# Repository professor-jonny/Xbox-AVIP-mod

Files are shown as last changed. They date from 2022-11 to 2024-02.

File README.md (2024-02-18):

# Xbox Avip mod
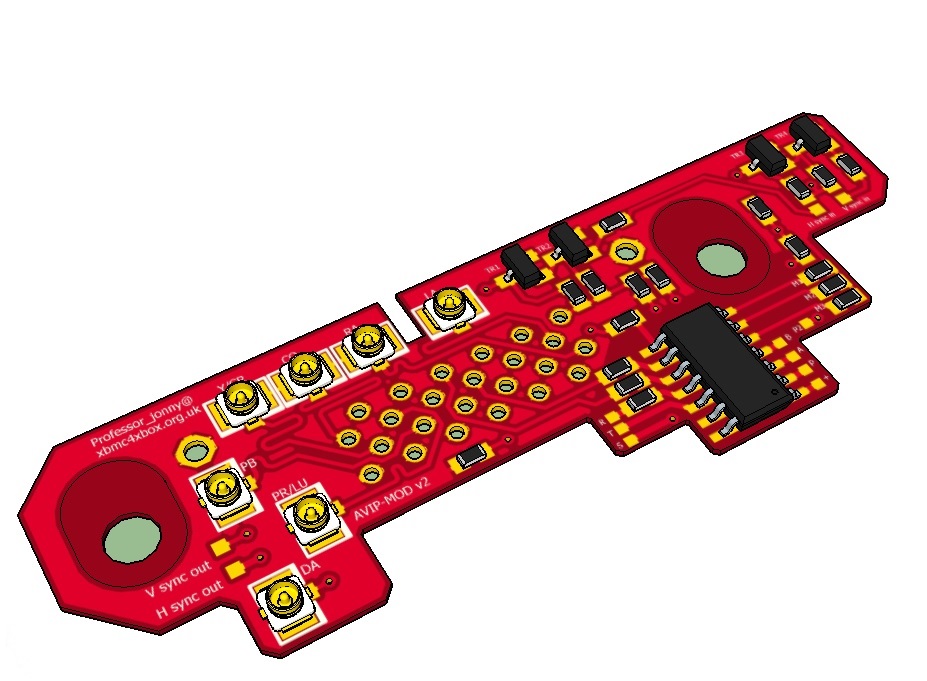
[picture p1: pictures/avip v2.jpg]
AVIP BRD


## Project Info
We all know that modern TV's are going away from component and composite video inputs in favor of newer technologies such as HDMI because of this there has been many people attempting various mods some great, some sketchy and some down right wrong.

This project started as I have seen a few people damage their Xbox consoles by attempting VGA and HDMI mods or made such a bad job of it that that I decided something needed to be done and I set out to make up a basic QSB to break out signals that you can use within the console to attached to external connectors or for use with an internal video adaptor solution.
Design goals were to be simple quick to install and have no complicated binary logic external switches to select the video modes.

The design also includes a buffer circuit to drive the internal h and v sync signals to 5v to give you proper VGA compliant signals with a suitable bios.

The system includes a PICAXE microcontroller to be able to switch video modes and other trickery, I designed it using this over a traditional microcontroller for ease of a user to modify using a three wire serial connection (in circuit) and partly from my lack of programming skills and time.
The PICAXE system enables any one to reprogram it without too much hassle and with minimal programming knowledge, both flow chart and basic programs are provided as samples that are easy to follow and understand.

I have also designed some breakout boards to join to the AVIP mod board, or you could use get IPEX/ U.FL to solder tails to connect to some sort of internal adaptor or converter in my perisomal Xbox I milled pads to place IPEX/ U.FL sockets on a component to HDMI adaptor.

I had double ended U.FL /IPEX Connectors made for this project officially the connectors are actually 50 ohm but were made with 75 ohm cable so the impedances are not perfect but it was the only aspect of the project I was not happy with, I planned to further update this project with a flex or FFC cable between boards but I'm unsure on impedance matching and the design of such a cable if someone can offer us some help with that I would be very grateful.

I realize at 720p the bandwidth can tip 75MHZ so the cable will need to be designed with microstrip or stripline transmission mitred bends or as such but I don't know much about the property's of these FFC cables or FlexPCB's or their connectors.

## Rational over other mods
I realize that there are other mods that offer better solutions or something of a similar goal such as native digital output or internal component to HDMI etc... but many are not simple or cost effective.
Many require de-soldering the original AVIP connector or micro soldering and for many people this is something that is beyond their skill set but a QSB solution is very noob friendly and hence my project.

## Features
The AVIP  mod has the following features:
  * Pluggable RF connectors for AV signals.
  * Impedance matched shielded analogue signals.
  * Automatic selection of backup AV mode.
  * VGA compliant 5V buffered V and H sync signals (non inverted).
  * Video mode toggling.
  * Fits all motherboard revisions.
  * Additional optional audio and video breakout boards.
  * Open source design.
  * In circuit user reprogrammable.
  * Audible/ light mode indication options.
  * Expansion capabilities.
  * AV pack boot fix (boot console without AV pack fitted).
  * Ability to still use original AV packs with this mod fitted.
  * Still works with Light Guns with a suitable TV and connection.
  * auto reconfigure of mode selection on reboot of console.

## Break out boards
I have managed to design some break out boards for the system my goal was to design them to be panel mounting on the back of the Xbox and look as if they were part of the system and not a hackjob.
I managed to find vertical components for the Break Out PCB's so I could mount the Break out board's Panel mount direct on the back of the Xbox with a spacer as opposed to a right angle mount PCB sockets so all that one would need is bolts and some nylon spacers and a Dremel tool to fit them.

you will notice that the component board provides every signal via RCA connectors to the back of the Xbox and it has a gap on either side where I would suggest you could place something else there like a 3.5mm vertical socket to power an external HDMI adaptor.

## Variants
I have modified the original v2 design with just some minor changes to do with the weird package format 2n2222a transistors I originally brought that I could not find again on aliexpress.
I have created two new V4 design's, one top mounted option for use with the Open XHD project (currently unfinished) and a new design with a greatly simplified sync buffer circuit, be aware that both these options currently are un tested and released "as is"

## Eagle library's
Along with v3 and v4 models I decided to create a proper library for the AVIP footprints and create an actual schematic as I did the v1 and 2 designs straight from a PCB layout with the footprint done with vias on the board, yes shocking I know but I feel much better now with the later designs that someone can mess with them with a lot less difficulty.

## Notes
I have made a proto type V1 board and have sold a few and can be considered tested but I have not made a v2 design the version 2 design just adds a few features an components but is basically unchanged from a design perspective.
list of Changes:
  * resistors on the serial data lines to force the PICAXE to start-up in RUN mode with out an external jumper.
  * Mode select current limiting resistors for the AV pack mode lines (thanks Psycho-Chewbacca for the tip here).
  * + and - terminal for programming outside of the console.
  * capacitor added to make PCB fit nicer on V1.6 consoles (bottom variant only).
  * added notch to clear the support on the bottom of the case (also spaced apart the RF connectors).
  * reset line to LPC port to reboot PICAXE on reboot of console.
  * upped resistor sizes to make hand soldering possible (I found this out the hard way)

## Future plans
I thought of combining an XIRC into this as the m2 does virtual multitasking and has a learning IR code library embedded and a small EPROM to store IR codes it would just need to be connected to stand by power and a handful of components to remote power on the Xbox from an IR remote control, but for the time being ill leave that up to you guys to modify looking forward to seeing a version 2 from someone :-) it will require voltage clamps for the mode select pins as the standby voltage is 3.3v but the mode pins are 5v.

the inclusion of a video Buffer to drive the external signals is not a bad idea as officially if you connect a AV pack and a external device you are driving two impedance match signals from the same output on the Xbox this was not really the intention of the project I only intend to use one output at a time.

# Links to software
This PCB design was done in eagle which is free to use and can be found here:

[Autodesk Eagle]( https://www.autodesk.com/products/eagle/free-download)

The PICAXE was programmed with the PICAXE editor 6 which can be found here:

[PICAXE Editor 6](https://picaxe.com/software/picaxe/picaxe-editor-6/)

The PCB design was converted to a sketch-up model by using the Eagleup script you can find information on the install and usage of it here:

[Eagleup ](https://eagleup.wordpress.com/installation-and-setup/)

The 3D model was done with SketchUp and a 30 day trial can be found here:

[SketchUp Trial](https://www.sketchup.com/try-sketchup)

You may use the free online version here:

[SketchUp Free](https://www.sketchup.com/plans-and-pricing/sketchup-free)

## Installation and programming Manual
You can find the latest version of the Installation and programming manual here it has additional info not available in this read me:

[AVIP mod Google Docs Manual](https://docs.google.com/document/d/1ht77iEsDnr8k5D_PiUR8pX0tqKVkKB9yM1Bdu0-4m4M/edit?usp=sharing)

## pictures
There is a few sample pictures located [here](https://github.com/professor-jonny/Xbox-AVIP-mod/tree/main/pictures) in the repo and a few extra below:

VGA break out board:

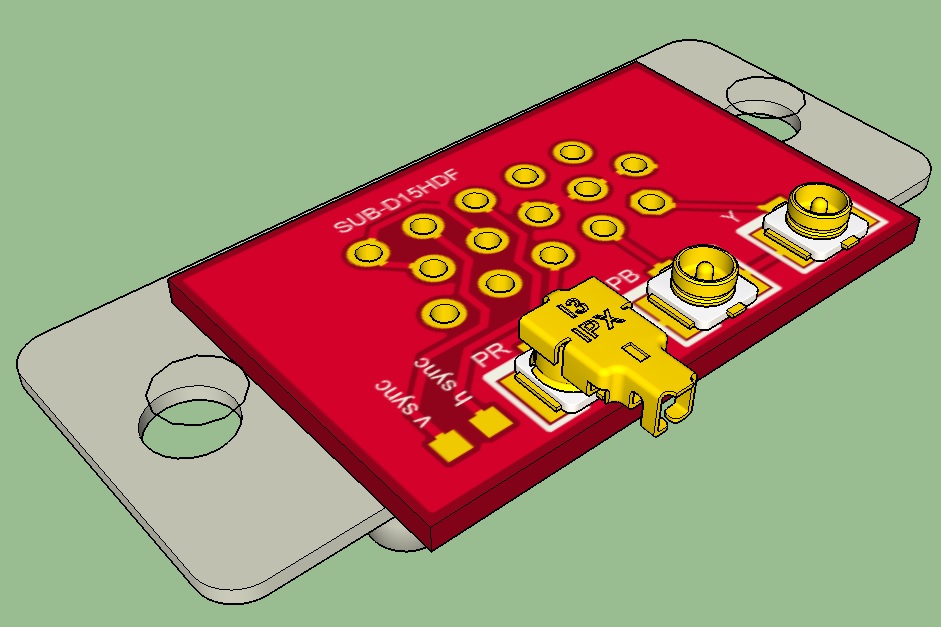
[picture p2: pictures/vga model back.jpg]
VGA


proto type v1:

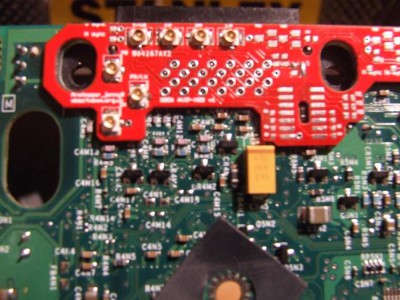
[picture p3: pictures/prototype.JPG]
PROTO v1


proto type v3:

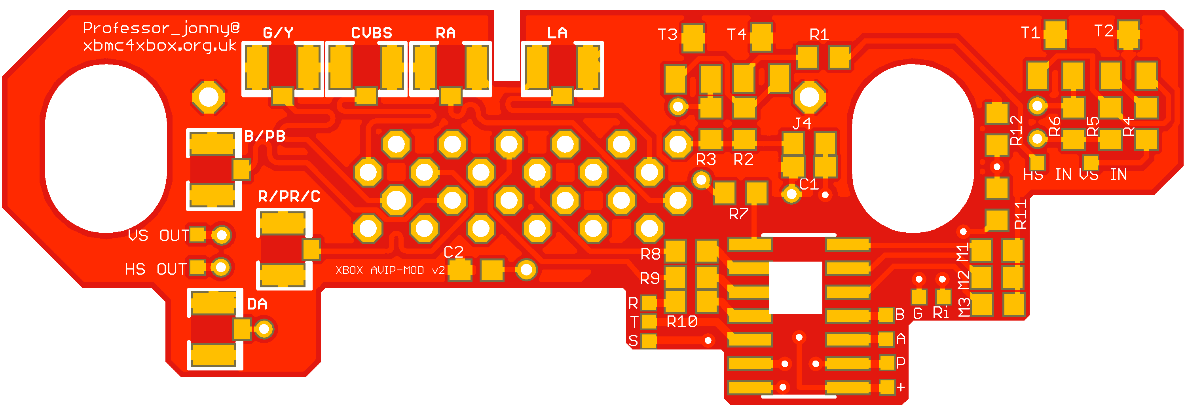
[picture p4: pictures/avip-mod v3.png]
PROTO v3


proto type v4:

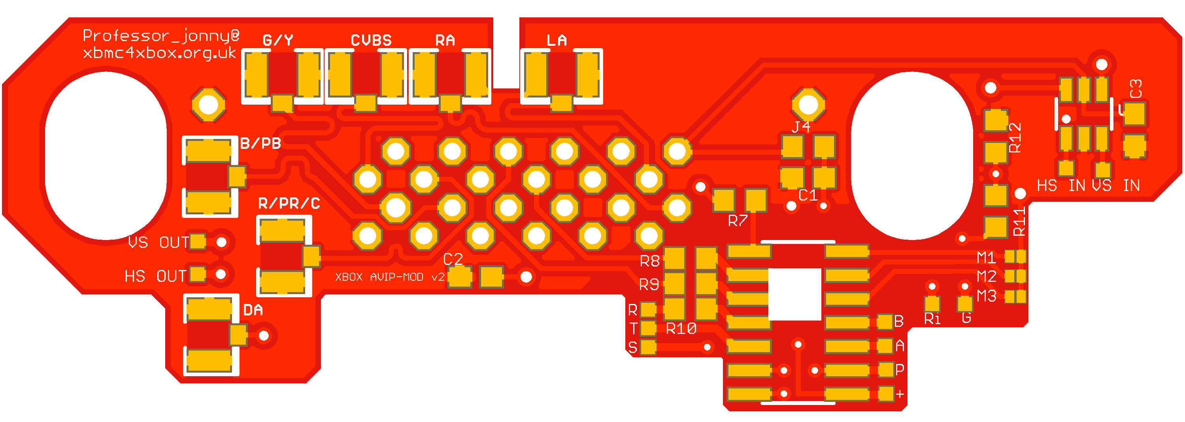
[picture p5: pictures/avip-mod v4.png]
PROTO v4


proto type v4 top:

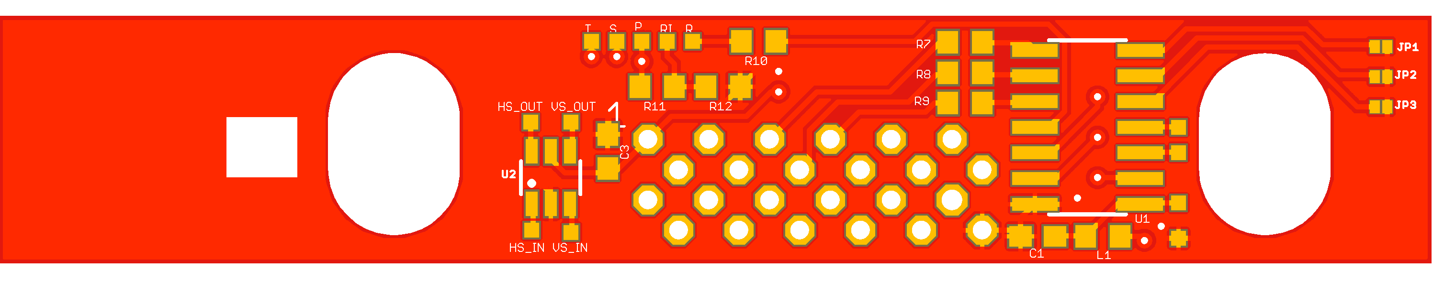
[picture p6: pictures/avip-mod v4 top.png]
PROTO v4 top


Wired to a component to HDMI adaptor:

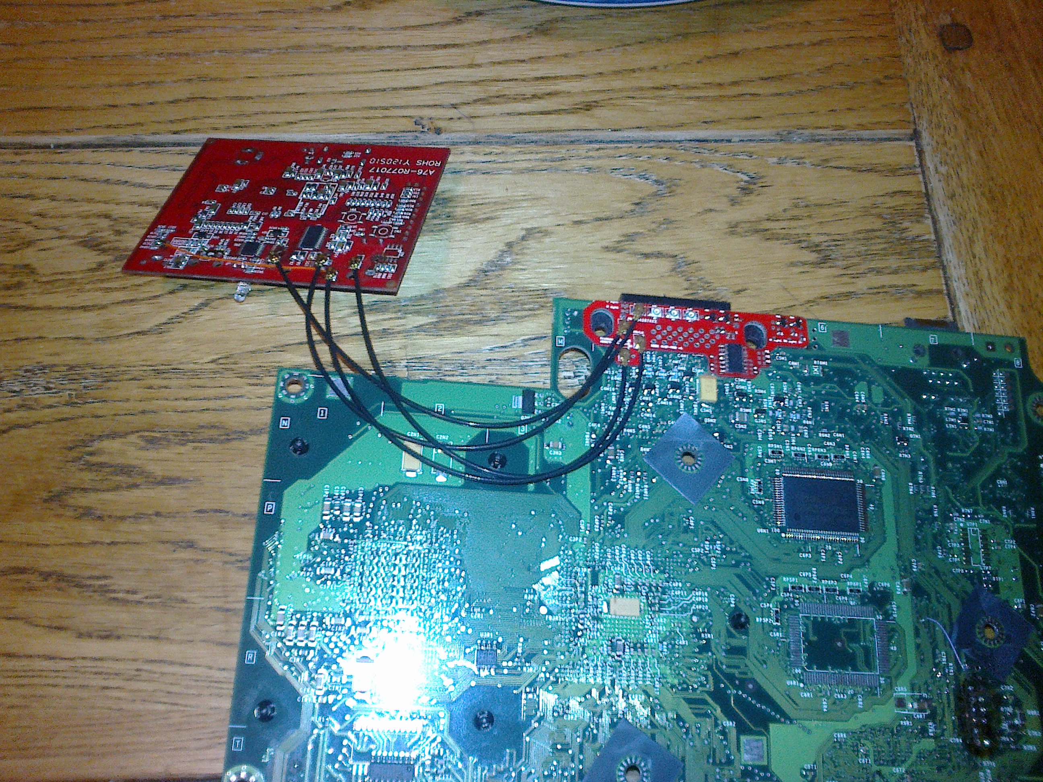
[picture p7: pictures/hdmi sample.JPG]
HDMI SAMPLE


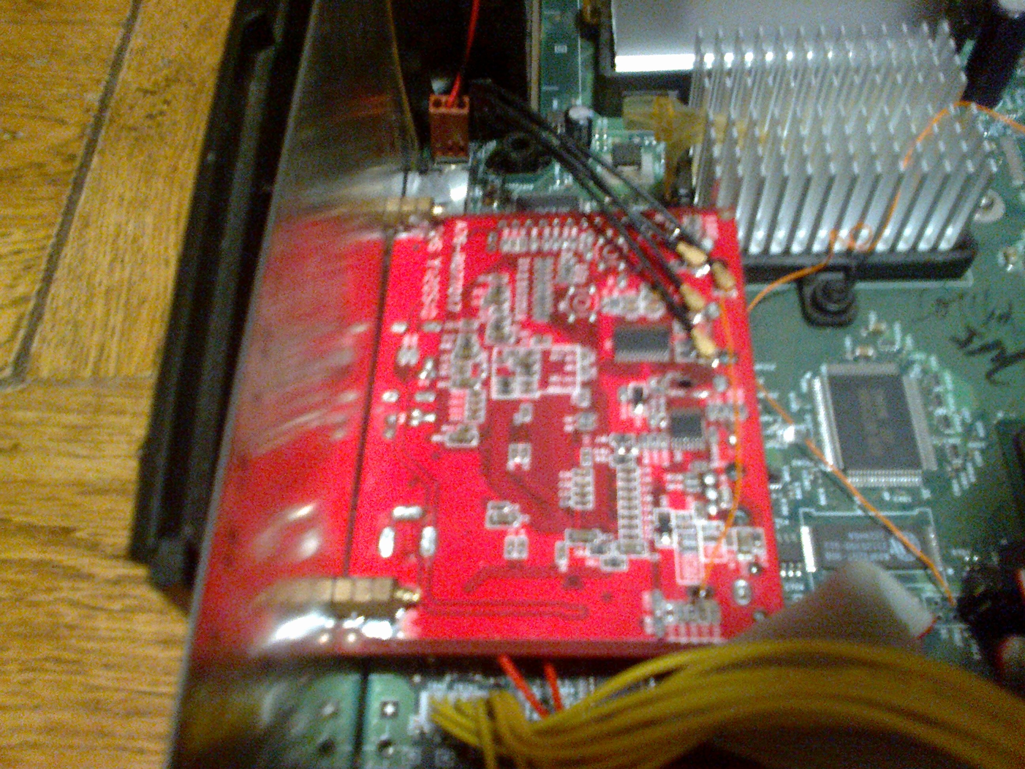
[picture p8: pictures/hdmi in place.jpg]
HDMI in place


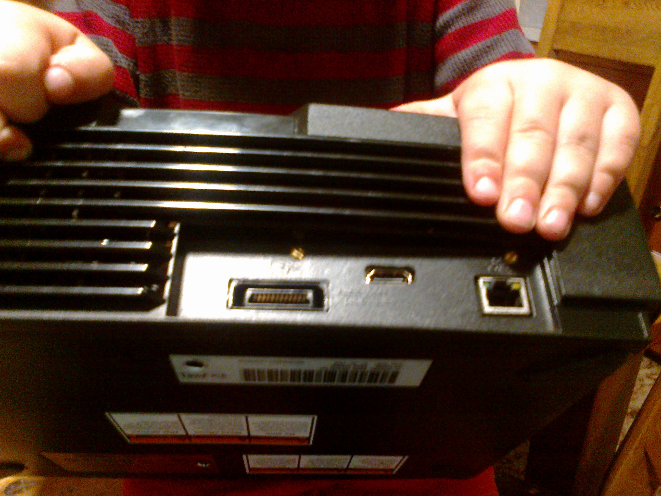
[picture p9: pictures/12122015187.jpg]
HDMI plug location


## Licensing
This Project is free and open source.
  *  Hardware is shared under the [CERN OHL version 2.0.](https://ohwr.org/cernohl).
  *  The PICAXE program is shared under [GPLv3](https://www.gnu.org/licenses/quick-guide-gplv3.en.html).

If you like my work please consider a small donation to the XBMC4XBOX forum or one of the many Great Xbox resources out there you may also send me sample of clones of this project or buckets or cash or what ever :-)

For those interested there is also a bit of a build log [here on the XBMC4XBOX forum](https://www.xbmc4xbox.org.uk/forum/viewtopic.php?f=13&t=3644&hilit=xbox+avip+mod )

Id Like to Thank all that have helped to get it where it is today and a shutout to he crew over at XBMC4XBOX and a thanks to Psycho-Chewbacca (AKA benny Diamond) for his help.

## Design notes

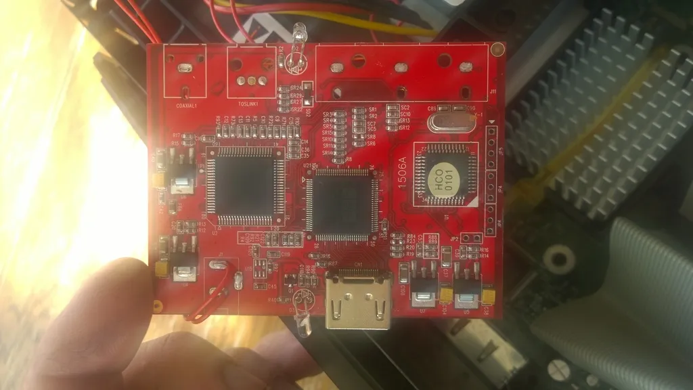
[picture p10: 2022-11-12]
pictures/hdmi bottom.jpg

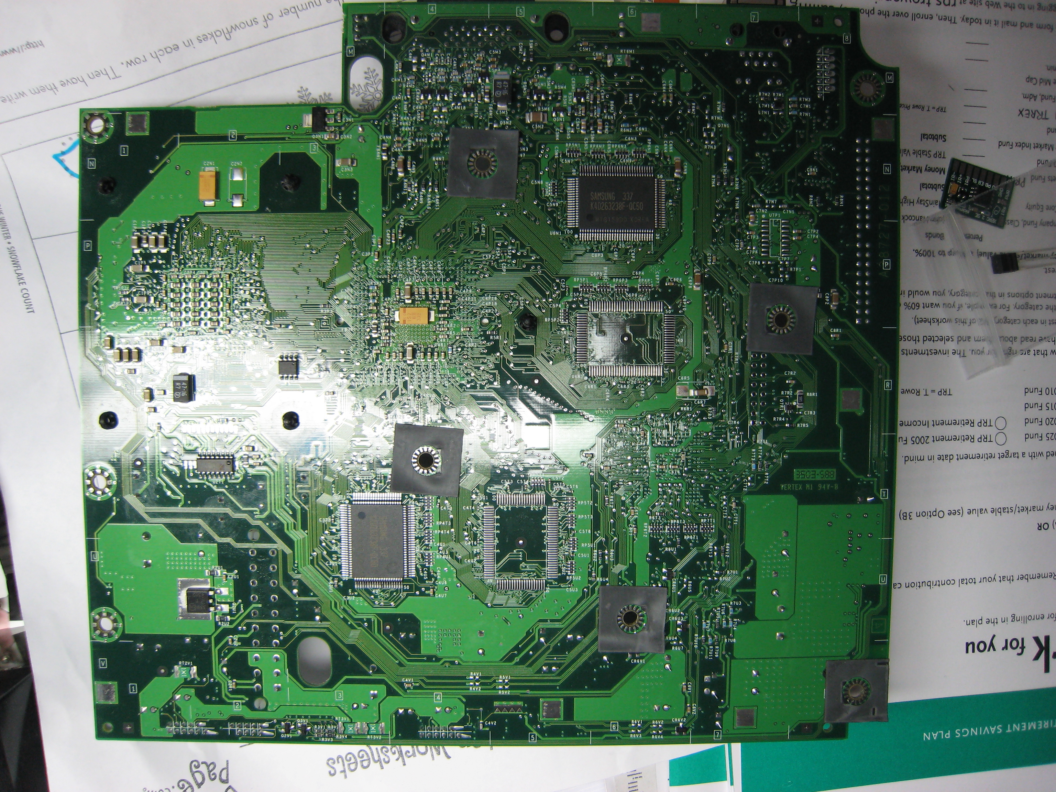
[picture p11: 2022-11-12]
pictures/xbox v1.-1.4 motherboard.jpg

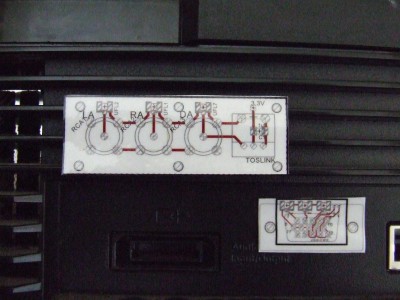
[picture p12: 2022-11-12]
pictures/vga location.jpg

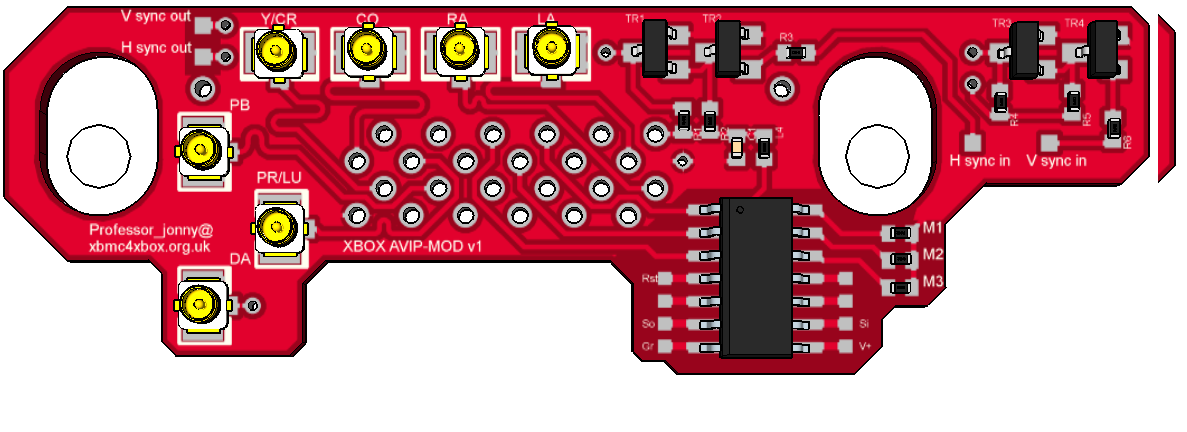
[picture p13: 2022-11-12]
pictures/populated pcb model.jpg

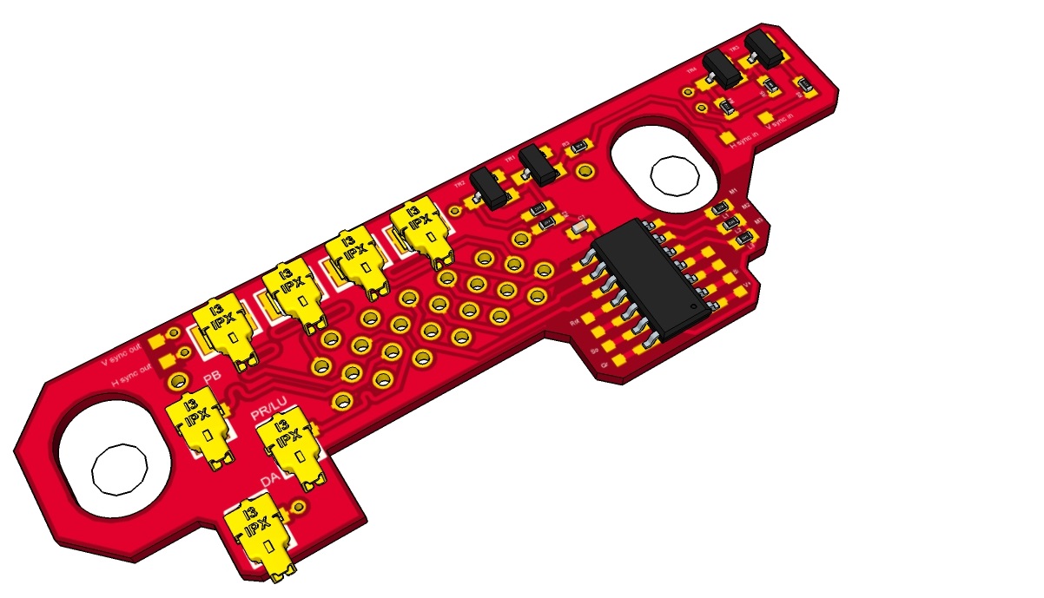
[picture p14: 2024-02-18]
pictures/avip v1.jpg

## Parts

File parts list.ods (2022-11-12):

AVIP-mod board
part | discription | Amount | disc
Micro | Picaxe 14M2 150 mil / 3.81 mm SOIC (SO-14) (AXE017M2SM ) | 1 | mode select micro
R1-R6 | 2k2ohm 0603 | 6 | pullups for sync buffer
R7-R9 | 1Mohm 0603 | 4 | current limiter to lcp rst and avip mode select term
R10 | 22Kohm 0603 | 1 | programming bypass resistor
R11 | 10kohm 0603 | 1 | programming bypass resistor
C1-C2 | 100nf 0603 | 1 | decoupling caps
L1-L3 | 0ohm 0603 | 3 | mode select jumpers
Y,PB,PR,CO,DA,LA,RA | U.fl IPX smd socket (U.FL-R-SMT-1) | 7 | video and audio conn
TR1,2,3,4 | 2N2222 sot23 | 4 | sync buffers
Component board
part | discription | Amount
RCA1,2,3,4,5,6,7,8,9 | BTOR 1 vertical rca connector | 9
Y,PB,PR,CO,DA,LA,RA | U.fl IPX smd socket (U.FL-R-SMT-1) | 7
toslink | DLT11B0A vertical toslink sender | 1 | toslink driver
C2 | 1uf 1206 | 1 | noise imunity for toslink
Vga board
part | discription | Amount
vga socket | DE-15 (17hd-015-S-AA-0-30) | 1
Y,PB,PR | U.fl IPX smd socket (U.FL-R-SMT-1) | 3
Sound board
part | discription | Amount
DA,LA,RA | U.fl IPX smd socket (U.FL-R-SMT-1) | 3
RCA1,2,3 | BTOR 1 vertical rca connector | 3
toslink | DLT11B0A vertical toslink sender | 1 | toslink driver
C2 | 1uf 1206 | 1 | noise imunity for toslink

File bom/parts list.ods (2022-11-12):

AVIP-mod board
part | discription | Amount
Micro | Picaxe 14M2 150 mil / 3.81 mm SOIC (SO-14) (AXE017M2SM ) | 1
R1-R6 | 2kohm 0402 | 6
C1 | 100nf 0402 | 1
L1-L4 | 0ohm 0402 | 3
Y,PB,PR,CO,DA,LA,RA | U.fl IPX smd socket (U.FL-R-SMT-1) | 7
TR1,2,3,4 | 2N2222 sot23 | 4
Component board
part | discription | Amount
RCA1,2,3,4,5,6,7,8,9 | BTOR 1 vertical rca connector | 9
Y,PB,PR,CO,DA,LA,RA | U.fl IPX smd socket (U.FL-R-SMT-1) | 7
toslink | DLT11B0A vertical toslink sender | 1
C2 | 1uf 1206 | 1
Vga board
part | discription | Amount
vga socket | DE-15 (17hd-015-S-AA-0-30) | 1
Y,PB,PR | U.fl IPX smd socket (U.FL-R-SMT-1) | 3
Sound board
part | discription | Amount
DA,LA,RA | U.fl IPX smd socket (U.FL-R-SMT-1) | 3
RCA1,2,3 | BTOR 1 vertical rca connector | 3
toslink | DLT11B0A | 1

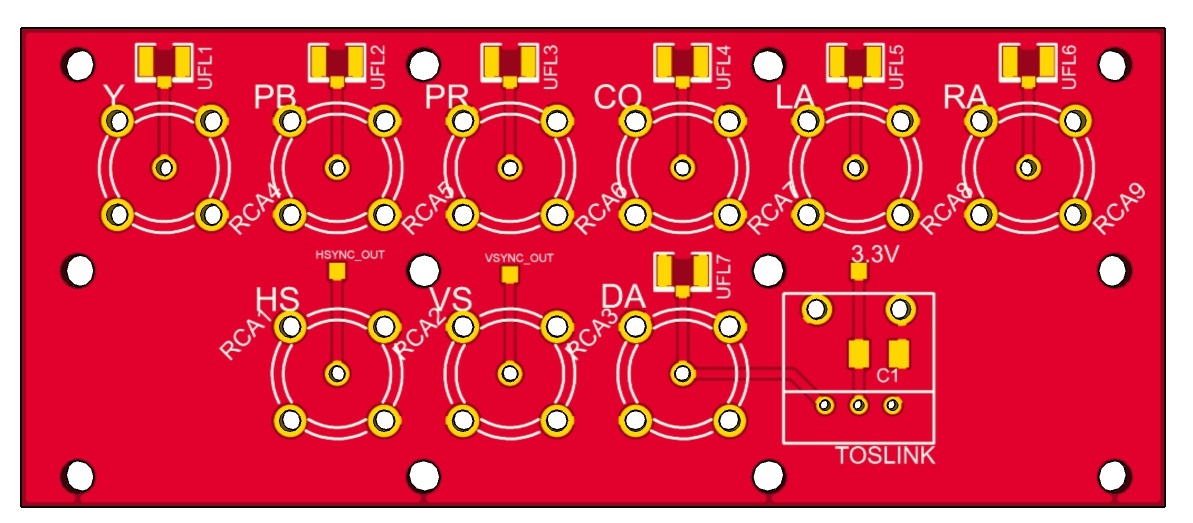
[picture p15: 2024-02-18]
pictures/component board.jpg

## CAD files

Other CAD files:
3d model/avip mod v2.skp
3d model/avip-mod v1.skp

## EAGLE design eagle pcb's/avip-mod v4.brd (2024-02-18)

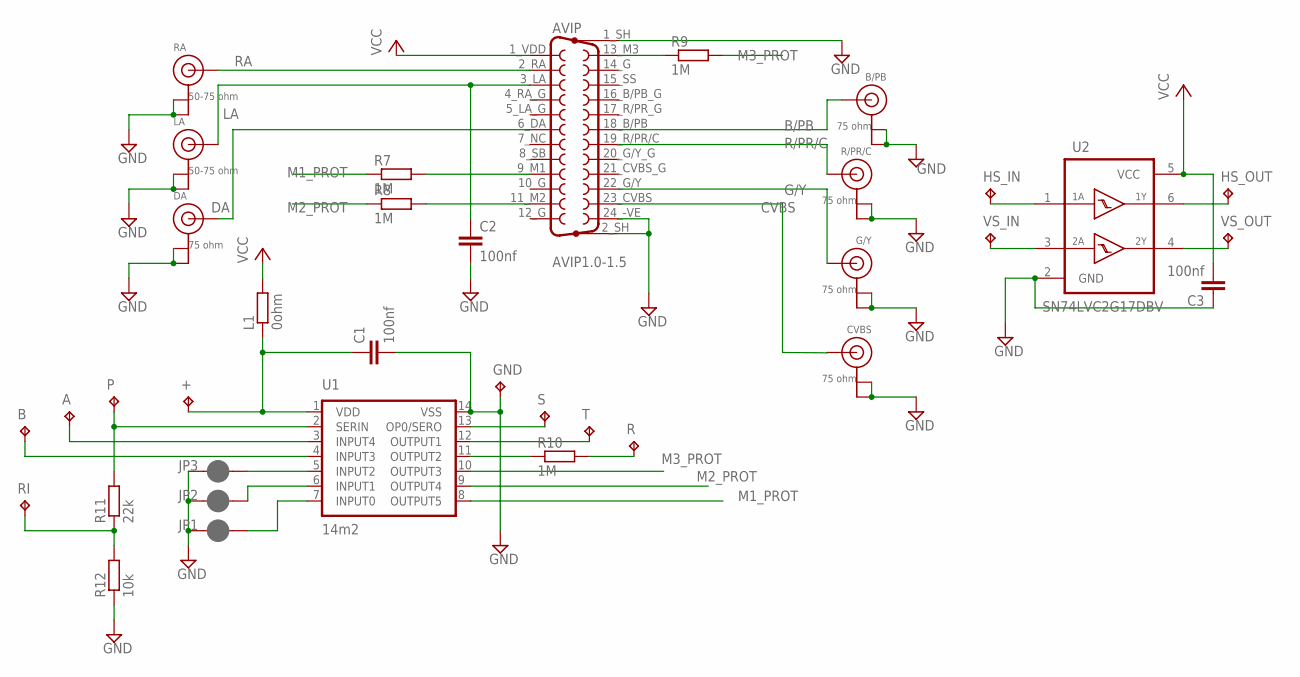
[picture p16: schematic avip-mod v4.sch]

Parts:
+: TPTP07SQ; TP07SQ
A: TPTP07SQ; TP07SQ
AVIP: AVIP1.0-1.5; AVIP-1.0-1.5
B: TPTP07SQ; TP07SQ
B/PB: 75 ohm; U.FL
C1, C2, C3: 100nf; C0603
CVBS: 75 ohm; U.FL
DA: 75 ohm; U.FL
G/Y: 75 ohm; U.FL
GND: TPTP07SQ; TP07SQ
HS_IN: TPTP07SQ; TP07SQ
HS_OUT: TPTP07SQ; TP07SQ
JP1, JP2, JP3: JUMPER-SMT_NO-SILK; SMT-JUMPER
L1: 0ohm; R0603
LA: 50-75 ohm; U.FL
P: TPTP07SQ; TP07SQ
R: TPTP07SQ; TP07SQ
R7, R8, R9, R10: 1M; R0603
R11: 22k; R0603
R12: 10k; R0603
R/PR/C: 75 ohm; U.FL
RA: 50-75 ohm; U.FL
RI: TPTP07SQ; TP07SQ
S: TPTP07SQ; TP07SQ
T: TPTP07SQ; TP07SQ
U1: 14m2; SO14
U2: SN74LVC2G17DBV; SOT23-6
VS_IN: TPTP07SQ; TP07SQ
VS_OUT: TPTP07SQ; TP07SQ

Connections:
A: A.TP, U1.3 (INPUT4)
B: B.TP, U1.4 (INPUT3)
B/PB: AVIP.18_B/PB, B/PB.3 (SIGNAL)
CVBS: AVIP.23_CVBS, CVBS.3 (SIGNAL)
DA: AVIP.6_DA, DA.3 (SIGNAL)
G/Y: AVIP.22_G/Y, G/Y.3 (SIGNAL)
GND: AVIP.1_SH, AVIP.2_SH, AVIP.24_-VE (25_VSS), B/PB.1 (GND), B/PB.2 (GND), C1.2, C2.2, C3.1, CVBS.1 (GND), CVBS.2 (GND), DA.1 (GND), DA.2 (GND), G/Y.1 (GND), G/Y.2 (GND), GND.TP, JP1.1, JP2.1, JP3.1, LA.1 (GND), LA.2 (GND), R12.1, R/PR/C.1 (GND), R/PR/C.2 (GND), RA.1 (GND), RA.2 (GND), U1.14 (VSS), U2.2 (GND)
H_SYNC_IN: HS_IN.TP, U2.1 (1A)
H_SYNC_OUT: HS_OUT.TP, U2.6 (1Y)
LA: AVIP.3_LA, C2.1, LA.3 (SIGNAL)
M1: AVIP.9_M1, R7.2
M1S: JP1.2, U1.7 (INPUT0)
M1_PROT: R7.1, U1.8 (OUTPUT5)
M2: AVIP.11_M2, R8.2
M2S: JP2.2, U1.6 (INPUT1)
M2_PROT: R8.1, U1.9 (OUTPUT4)
M3: AVIP.13_M3, R9.1
M3S: JP3.2, U1.5 (INPUT2)
M3_PROT: R9.2, U1.10 (OUTPUT3)
PROG: P.TP, R11.2, U1.2 (SERIN)
R/PR/C: AVIP.19_R/PR/C, R/PR/C.3 (SIGNAL)
RA: AVIP.2_RA, RA.3 (SIGNAL)
RESET: R.TP, R10.2
RESET_PROT: R10.1, U1.11 (OUTPUT2)
RING: R11.1, R12.2, RI.TP
SPEAK: S.TP, U1.13 (OP0/SERO)
TOGGLE: T.TP, U1.12 (OUTPUT1)
VCC: AVIP.1_VDD, C3.2, L1.2, U2.5 (VCC)
VDD: +.TP, C1.1, L1.1, U1.1 (VDD)
V_SYNC_IN: U2.3 (2A), VS_IN.TP
V_SYNC_OUT: U2.4 (2Y), VS_OUT.TP

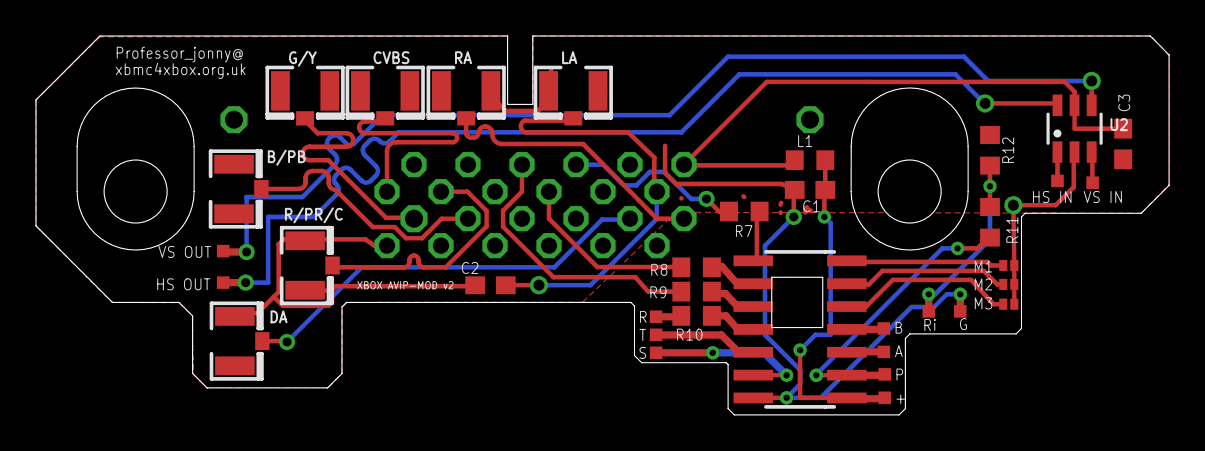
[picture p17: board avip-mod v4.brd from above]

Board: 2 copper layers, 63.0 x 21.1 mm, 36 parts (1 on the bottom side), 31 nets.

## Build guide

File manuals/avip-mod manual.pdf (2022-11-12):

## XBOX AVIP-MOD V1 MANUAL (PRE RELEASE BETA)

Background.
This project stemmed from the need to find an easy way of connecting external Video\audio devices to the Xbox console, as the Xbox is out of production it is becoming ever hard to find good quality component cables and with TV's now starting to do away with these legacy inputs something needed to be done.

I have seen many home hacks to implement internal and external video mods to the console some have looked like they did not instill reliability or great signal integrity or have ended up in damage to the Xbox console either from incorrect installation or iron damage.

This adapter/ quick solder board will make it easy implement internal video adapters or to attach a custom connector to the Xbox with minimal of fuss and will provide great signal integrity with an almost Idiot proof installation.

Note: the AVIP-MOD has not yet been tested and may not function it is still in the development stages and I'm waiting to receive sample PCB's to test their suitability but from initial testing this product should work as intended.
Features.
Below is a list of general features:
1. Pluggable RF connectors for AV signals.
1. Impedance matched shielded analogue signals.
1. Automatic selection of backup AV mode.
1. VGA compliant 5V buffered V and H sync signals (non inverted)
1. Video mode toggling
1. Fits all motherboard revisions
1. Additional optional audio and video breakout boards
1. Open source design.
1. In circuit user reprogrammable.
2. Audible/ light mode indication options.
3. Expansion capabilities
4. AV pack boot fix (boot console without av pack fitted)

Once the board is in place and connected to the Xbox console the video signals are connected to the adapter board using miniature plug-gable RF connectors, semi making the solution plug and play by the installer.

In addition to these features I decided to include buffered Hsync and Vsync signals so that if someone wished they could implement proper VGA compliant signals (using a suitable bios, that is.)

The device is somewhat intelligent, it has the ability to detect if an AV pack is connected to the Xbox console and enable that output, if no pack is detected on startup or reset the Xbox will automatically select an appropriate mode base on the mode select jumpers M1,M2 and M3.

If an external push button is connected and operated upon power up of the console and no av pack is detected the AVIP-MOD will change into toggle mode, in toggle mode additional presses of the mode button will cycle through all the available AV pack types to manually.

The Hardware.
This project was based around the SMD version of the Picaxe 14M2 (AXE017M2SM) , sure the programming gurus are going to to flame me and say “what the hell did you do that for?”
The reasoning is that:
- with little knowledge in micro controllers could modify the program at home in circuit with free tools and there is not a steep learning curve as there is in C or assembler.
- the use of expensive external programmers are not needed; many of the users and modders of Xbox consoles are not electronics engineers or embedded software engineers and this enables them to play and make modifications to the program.
Programming.
The AVIP-MOD comes pre-programmed and no programming is required by the installer, but if a user wishes to customize the program they can. Below is the diagram for the connection to the Picaxe programming cable:

The Picaxe programming cable is fitted with a headphone type 3.5mm male plug and its terminals

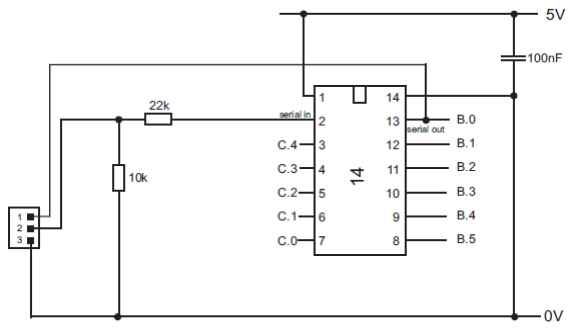
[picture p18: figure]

are as follows:

Pin 1 tip

Pin 2 ring
Pin 3 ground

when you are finished programming serial in must be tied back to ground to enable normal operation.
Programming Software.
The following software can be used to program the AVIP-MOD board

PICAXE Editor 6 (windows)
PICAXE Programming Editor (windows)
AXEpad (multi platform)

For more information on programming and the Picaxe platform see http://www.picaxe.com/

Installation and configuration.
board layout diagram

Below is the pinout of the Picaxe microcontroller used on the AVIP-MOD board with the standard program (notice this is upside down to the above picture).

Pin description:

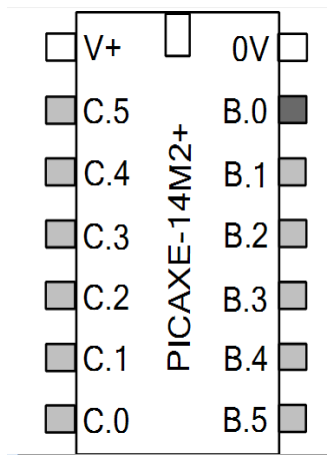
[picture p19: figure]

B3,b5,B5 Mode select input output pins used as inputs to detect presence of Xbox AV pack, also used as outputs to force mode during auto select mode.

C2,C1,C0 Mode select jumper for default av pack type to select during auto select mode (see mode selection jumpers to configure pack type)

B2 | Reset pin to restart mode detection.
C5 | Serial input pin (programming use) ground during normal operation.
C4 | Enable toggle mode on start up and toggle mode mode change button during toggle mode.
C5 | Serial input pin tie to ground during normal operation.
B0 | Serial output pin/ Beep output leave floating during normal operation else connect to piezo
buzzer/ led to enable beep code/ flash on mode select or change.

Prior to installation the mode select jumpers need to be configured to select the correct AV mode when a pack is not detected on startup this is done using the mode jumpers M1,M2 and M3 below is a truth table table showing the mode select options:

M1 | M2 | M3 | mode
Off | On | On | Standard AV
Off | Off | On | Advanced AV
On | Off | Off | Component AV
Off | On | Off | VGAAV
Off | Off | Off | RGB AV

Installation may depend on the users needs/wants but basic installation is as below, the only connection that must be made is the connection of the serial in pin to ground to tell the micro to start up in run mode instead of programming mode.

The sync signals are present on pin 35 (H sync) Pin 36 (V sync) on the conexant video encoder chip so there are possibilities that these are not quite the same on all Xbox versions but are in the same general area and the use of a multimeter will confirm this.

Suggestions for installation/ programming.

The most common method of installation I see is this being used with is a breakout board to fit an internal component to HDMI adapter as new TV models are being released without component inputs. This is a good solution to overcoming this problem and if you have HDMI do you really need any other output modes?

After installation it is recommended that the RF connector plugs are secured so that they may not come loose if the Xbox is dropped or the RF cables pulled. Under normal circumstances they should never come loose but a short on the motherboard could render the Xbox dead or possibly damage the device the Xbox is connected to.

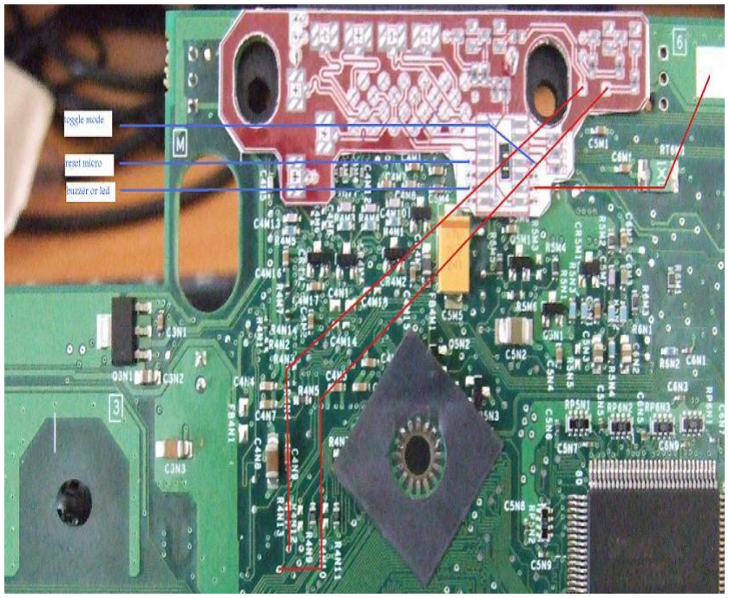
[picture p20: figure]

I would recommend putting foam tape on the bottom shielding to secure the plugs as a precaution and placing tape on any solder point to secure it from fracture or vibration damage.

The mode select jumpers could be connected to a binary switch, Xblast /Smart XX mod chip, Xerc or other such device and with this you could change the default AV pack mode at will, Unused pins on the board could be used for anything the user can think of.

The micro could be adapted to become an Xerc as there are libraries in the Picaxe chip to read an IR remote. This would require a few hardware mods but I’ll leave that up to you for a version 2 mod. I look forward to seeing program changes and hardware mods.

One issue with including an XERC on this board is that the Xbox standby is 3.3v and the input voltage from the AVIP mode pins is 5v and as the micro contains EMC/TVs diodes in the input circuit, this means the inputs can't tolerate supply voltages above VCC and damage may result to the micro. This could be fixed with voltage dividers on the mode select pins, a hardware revision would be required for this function.

The program could be modified to include an ADC converter to select an av mode via an adjustment pot, i2c, external Eeprom or control from another device such as a mod chip.

Yes, you could connect A LCD character display display to the AVIP-MOD to show the video mode selected but your programming resources would be best spent integrating those features into Xblast OS or XBMC4XBOX, lets not get too carried away here :-)

Other info.

Warning: this project is offered as is without warranty of any kind either expressed or implied.
I am open to criticism but don’t blame me if you blow up your Xbox.

This project is in no way complete. Use caution with any information contained in this document or any info you find about this project I can't guarantee it is accurate. Please take caution as I have not actually built and tested this actually works yet, but I don’t see why it would not.

You may contact me as professor_jonny on the XBMC4XBOX forums if you wish if you have any questions or possible feature or programming requests.

This project is released as open source. You can do with this as you like but you must show some love to xbmc4xbox forum donation box, and give me credit where due.

If you modify it this manual or PCB files you must make them available to everyone you may provide me with a copy also or a link to download.

If you start making this for commercial gain you must show some love to xbmc4xbox forum donation box, and give me credit where due, and I would love samples and a small bucket of cash :-).

Note that the routing on the AVIP board is quite tight fit and you may need to do trimming of the black posts on the case and it would be a good idea to place foam on the underside of the motherboard to stop the plugs from coming off and damaging your Xbox by shorting on the Xbox motherboard.

This project is is inspired by my love of the Xbox and my favorite software XBMC4XBOX.

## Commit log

2022-11-12 Initial commit
    Add README.md
    Init import of AVIP mod project.
    [avip mod v2.skp, avip no micro.brd, avip-mod v1.brd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]
2024-02-13 schematic sync and new PCB layout and footprint
    update the project and sync the schematic to the pcb with new lib for the AVIP connector.
    AVIP was done before in pads and vias fixed it up properly with a valid footprint
    Replaced the transistors with 2n2222 could not source the original ones and have been discontinued (note new layout for transistors to suit.)
    Fixed up a few DRC rules and made solder mask cover vias.
    [avip no micro.brd, avip-mod v1.brd, avip-mod v2.brd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]
2024-02-15 Update project
    Add Chihiro and 1.6 console footprints to AVIP library.
    Add alternative v4 Schmitt Trigger buffer circuit saves plenty of space on the PCB will come in handy with top design PCB in future.
    Update libs and PCB
    Add jumper pads instead of 0 ohm resistors to save space.
    optimize PCB layout and fix DRC errors
    [avip-mod v4.brd, avip-mod v4.sch]
2024-02-16 Updates
    Combined non stock items into single lib.
    update pcb, clean up some more DRC issues.
    reroute some traces to simplify design.
    [avip-mod v4.brd, avip-mod v4.sch]
2024-02-16 create new top motherboard variant
    Create new top motherboard variant for use with Open-XHD project.
    updated library with more Xbox AVIP footprints with removed shields.
    updated read me.
    [avip-mod v4 top.brd, avip-mod v4 top.sch]
2024-02-18 Fix PCB preview and update pictures
    Conflict between mill and dimensions layer causing all PCB's to not show up in manufacture preview.
    Add pictures of v3, v4 and v4 top PCB.
    [avip-mod v3.brd, avip-mod v3.sch, avip-mod v4 top.brd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]
